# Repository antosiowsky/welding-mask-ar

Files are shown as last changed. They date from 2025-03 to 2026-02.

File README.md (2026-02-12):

# 🛡️ AR Welding Helmet
### Welding Helmet with Augmented Reality (AR) Supporting Electric Arc Welding






## 📖 Abstract
**Bachelor's Thesis Project**

The aim of this project was to design and construct a welding helmet utilizing **Augmented Reality (AR)** technology in **Video Pass-Through** mode. The system eliminates the risk of flash blindness by replacing the traditional optical path with a digital vision system using a **Global Shutter camera**.

The device features a custom-made PCB, a hybrid power supply with **Energy Harvesting** (solar panel), and environmental sensors (gas, light). The software runs on a **Raspberry Pi Zero 2 W**, utilizing direct framebuffer access to achieve low-latency stereoscopic vision.

---

## ⚙️ Hardware Architecture

### Core Components
* **SBC:** Raspberry Pi Zero 2 W
* **Camera:** Raspberry Pi Global Shutter Camera (Sony IMX296) + ND 2-1000 Filter
* **Display:** 5.5" HDMI AMOLED (1920x1080)
* **ADC:** MCP3008 (SPI interface)

### Sensors & Power
* **Gas Sensor:** MQ-07 (Carbon Monoxide)
* **Light Sensor:** Photoresistor (Trigger for AGC)
* **Energy Harvesting:** Polycrystalline Solar Panel
* **Power:** Li-Ion 18650 Cells + BMS

### Wiring Diagram
The electrical connection between the Raspberry Pi and the analog sensors via the MCP3008 ADC.
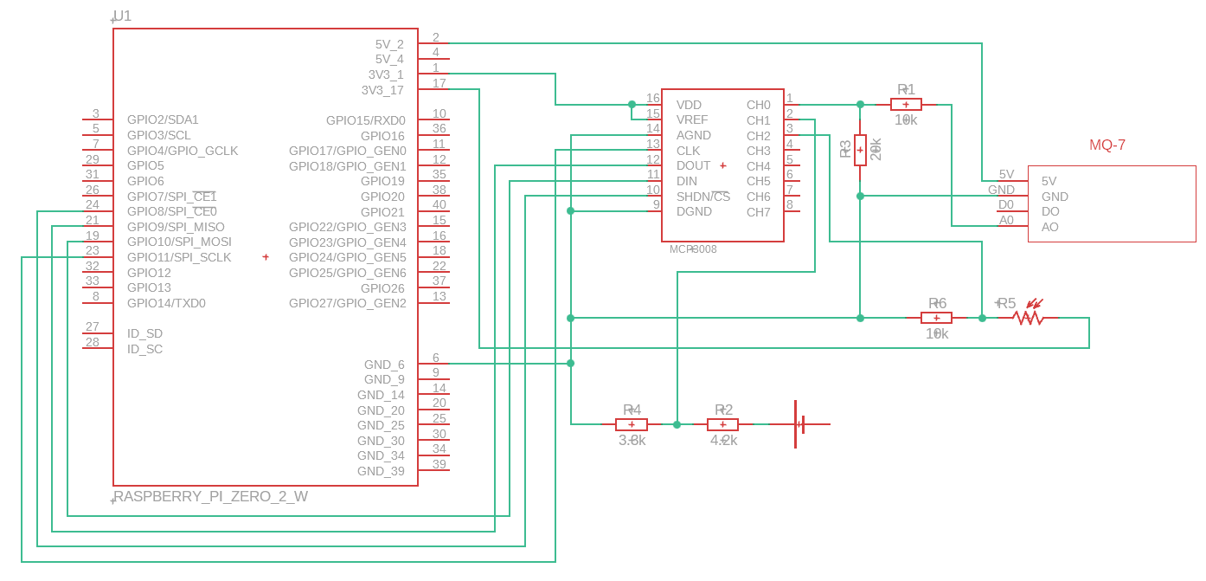
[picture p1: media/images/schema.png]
Schematic


### Custom PCB
The motherboard was designed in **Autodesk Fusion 360** and manufactured using a custom **laser ablation method** combined with chemical etching.

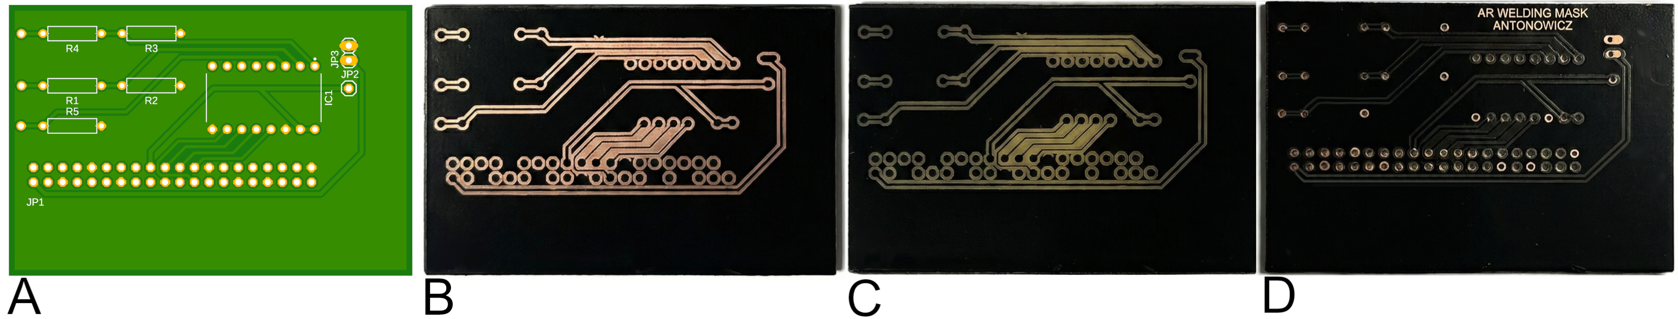
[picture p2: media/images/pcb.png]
Custom PCB Process


---

## 🛠️ Software & Algorithms

The control software is written in **Python** and optimized for the limited resources of the RPi Zero 2 W.

* **Direct Framebuffer Access:** Writing directly to `/dev/fb0` to bypass X11 overhead and minimize latency.
* **Adaptive Exposure Control (AEC):** Custom PID-like algorithm to adjust exposure time and gain in <100ms during arc ignition.
* **Multithreading:** Separated threads for image capture, data processing, and HUD rendering.
* **Stereoscopy:** Split-screen side-by-side rendering for VR optics compatibility.

### Dependencies
```text
opencv-python-headless
picamera2
spidev
numpy
```

## 📸 Gallery & Demo

### 1. The Prototype
The physical construction integrates standard welding protection with custom digital systems. The layout of the components is designed for optimal weight distribution and sensor accuracy.

| **Front View (External Sensors)** | **Internal Electronics & Optics** |
| :---: | :---: |
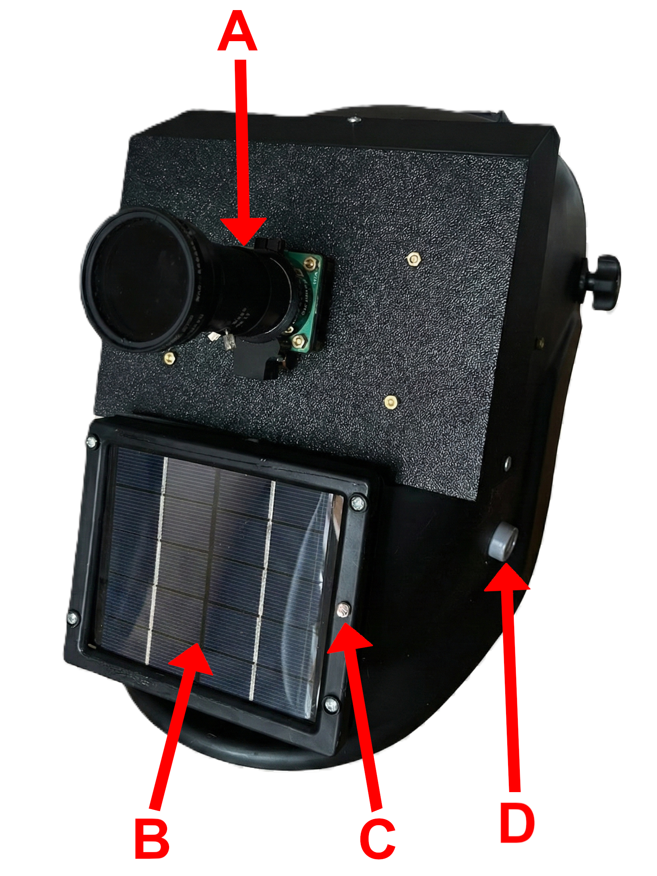
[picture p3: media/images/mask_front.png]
Front View
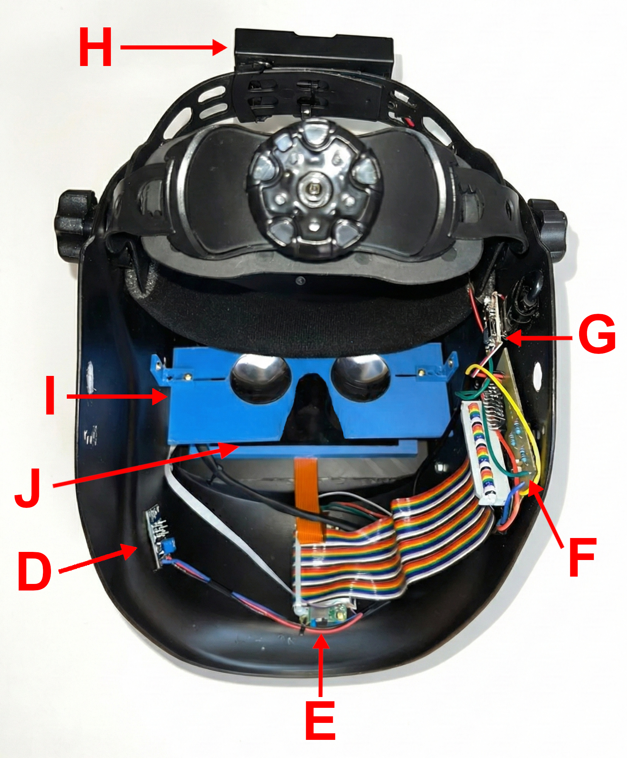
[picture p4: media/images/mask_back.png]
Internal Electronics
|  |  |

#### **Component Legend:**

**Front Panel (External):**
* **A) Camera Optical Assembly:** Raspberry Pi Global Shutter camera with UV protection and adjustable ND 2-1000 filter.
* **B) Solar Panel:** Polycrystalline silicon cell for Energy Harvesting.
* **C) Photoresistor:** Light intensity sensor acting as a trigger for exposure control algorithms.
* **D) MQ-07 Gas Sensor:** Carbon Monoxide monitoring inlet.

**Internal Layout:**
* **E) Central Processing Unit:** Raspberry Pi Zero 2 W.
* **F) Custom PCB:** Motherboard with integrated ADC, manufactured via laser ablation.
* **G) Power Management (BMS):** Module for energy distribution and solar charging control.
* **H) Energy Storage:** High-capacity Li-Ion 18650 battery pack.
* **I) VR Lens Assembly:** Biconvex lenses for comfortable eye accommodation at close display proximity.
* **J) 5.5" LCD Display:** Full HD panel responsible for rendering the AR HUD interface.

---

### 2. AR HUD Interface (Scenarios)
Visualization of the real-time data overlaid on the welder's field of view.

| **Arc Ignition (Initial Flash)** | **Stabilized View (Active AGC)** | **Gas Alarm (Safety Warning)** |
| :---: | :---: | :---: |
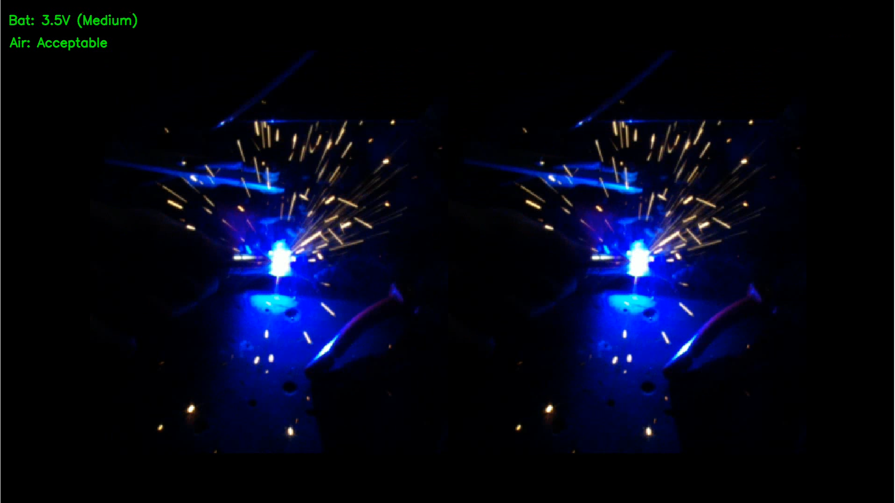
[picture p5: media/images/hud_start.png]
Flash
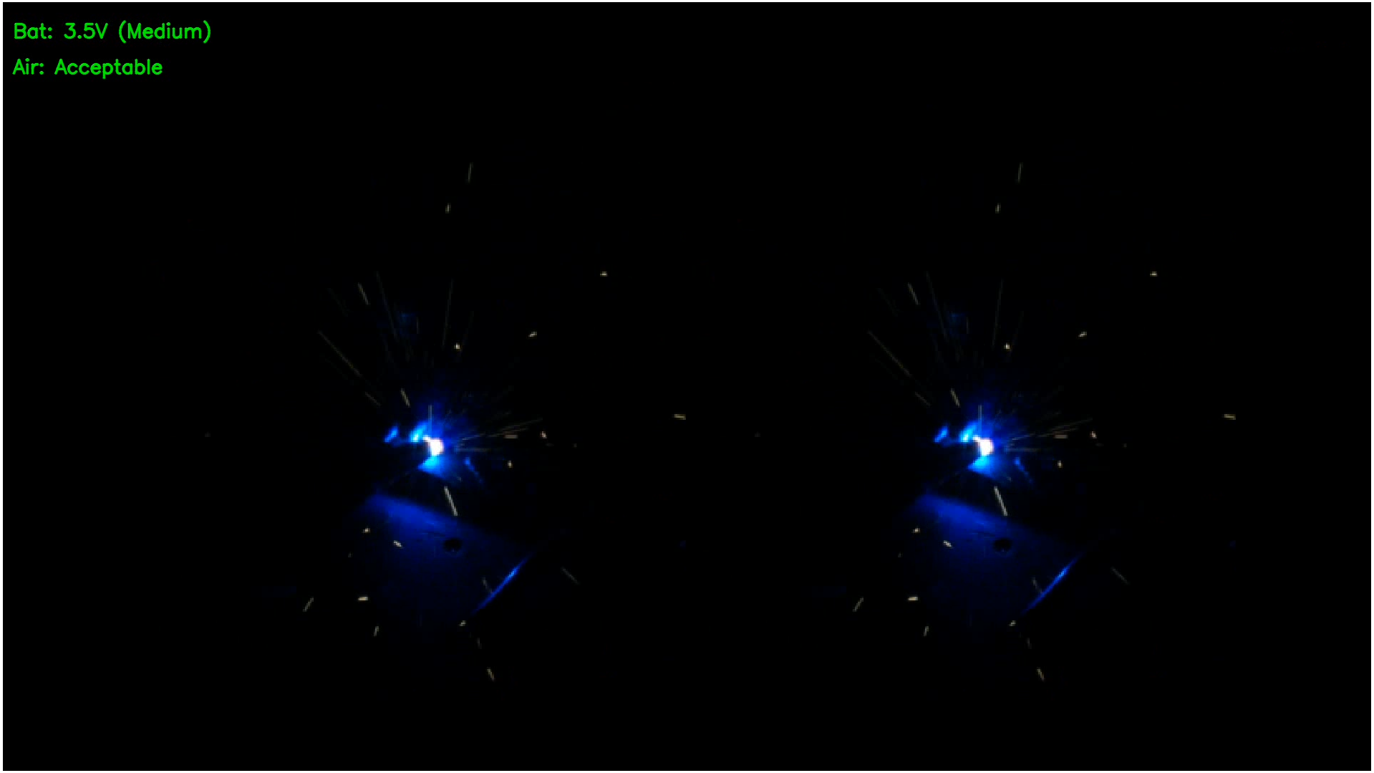
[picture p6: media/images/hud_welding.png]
Welding
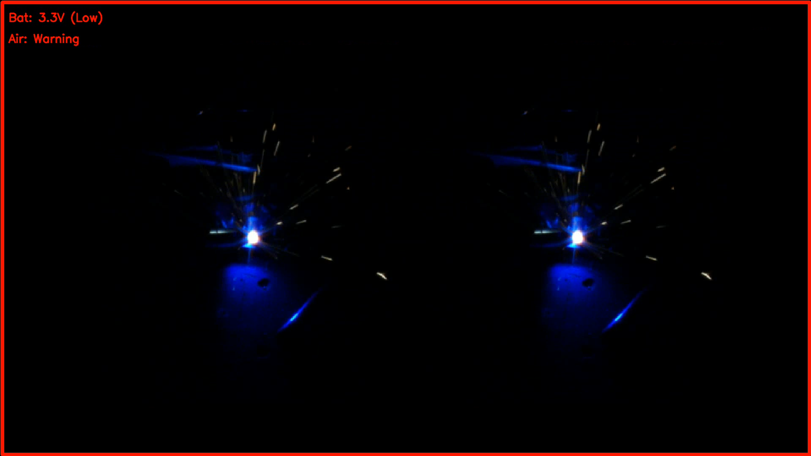
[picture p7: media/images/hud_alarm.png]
Alarm
|  |  |  |

### 3. Video Demonstration
System operation in real-time. The GIF below demonstrates the Adaptive Gain Control (AGC) reacting to the welding arc.

<div align="center">
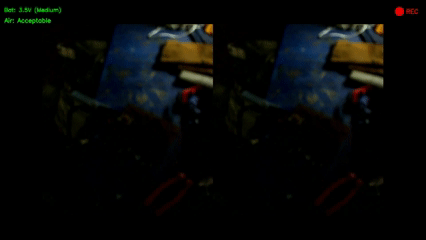
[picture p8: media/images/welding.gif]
Welding Demo GIF
  
</div>

> **Note:** The high-quality raw video file is available in the repository at: `media/video/demo.mp4`

---

## 📊 System Performance
Key metrics measured during validation tests:

| Metric | Result | Notes |
| :--- | :--- | :--- |
| **Glass-to-Glass Latency** | **60 - 90 ms** | Dependent on exposure time. Acceptable for MIG/MAG welding. |
| **Frame Rate** | **18 - 20 FPS** | Stable limit of RPi Zero 2W with dual-view rendering. |
| **Solar Charging** | **~150 mA** | Measured under welding arc simulation. Acts as a Range Extender. |
| **Gas Response Time** | **< 2.0 s** | Tested with butane/propane mixture. |

## 🏗️ Mechanical Design

The entire mechanical structure, including electronics enclosures and custom mounts, was designed in **Autodesk Fusion 360**. All components were optimized for 3D printing using **PET-G** and **PLA** filaments.

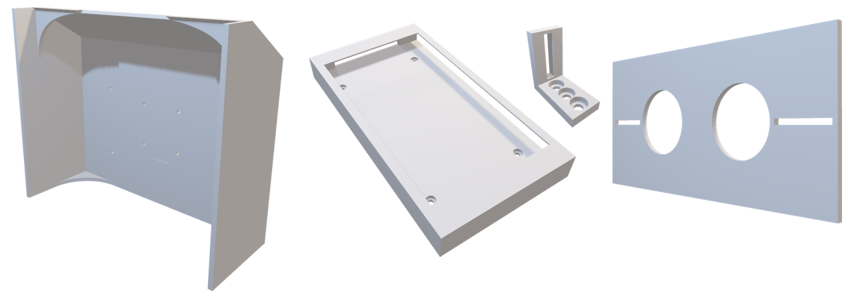
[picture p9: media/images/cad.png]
CAD Model


---

## 📄 License & Information

This project is open-source and available under the **MIT License**.

* **Author:** Jakub Antonowicz
* **University:** Silesian University of Technology (*Politechnika Śląska*)
* **Year:** 2026

---

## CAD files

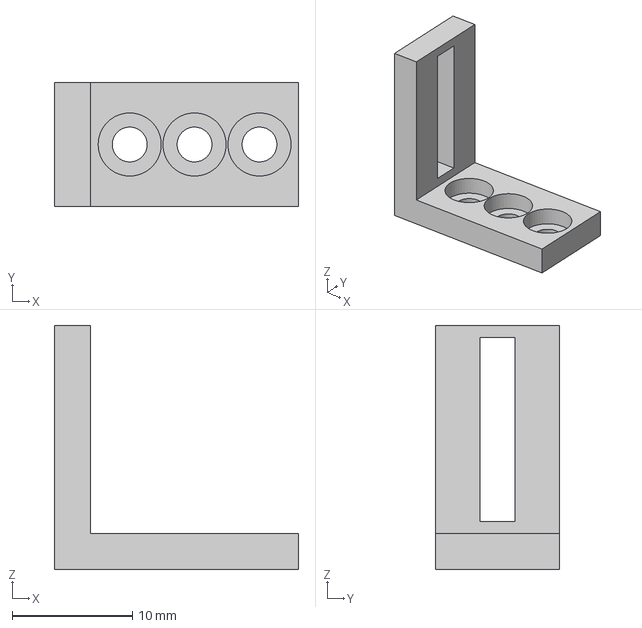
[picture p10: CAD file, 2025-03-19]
3d-models/support-angle.3mf
20.3 x 10.3 x 20.3 mm

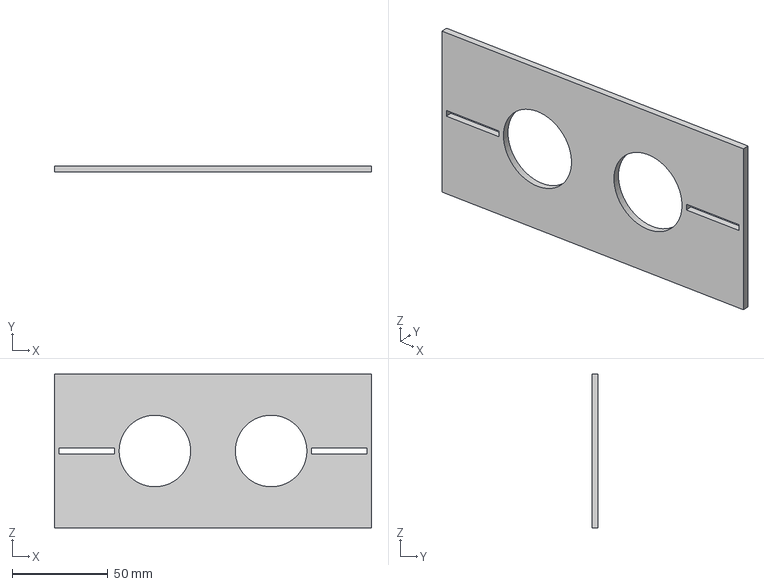
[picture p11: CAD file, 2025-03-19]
3d-models/case-lens.3mf
165.3 x 3.20 x 80.3 mm

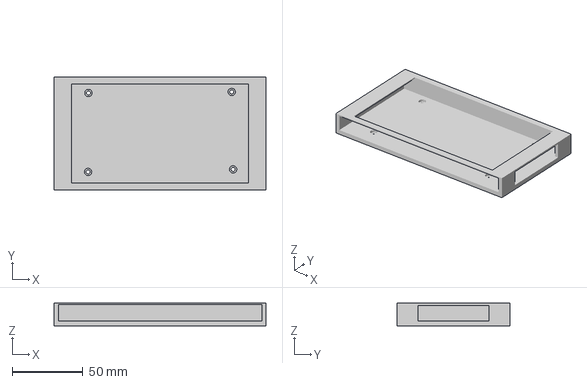
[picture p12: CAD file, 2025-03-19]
3d-models/case-display.3mf
150.0 x 80.0 x 16.0 mm

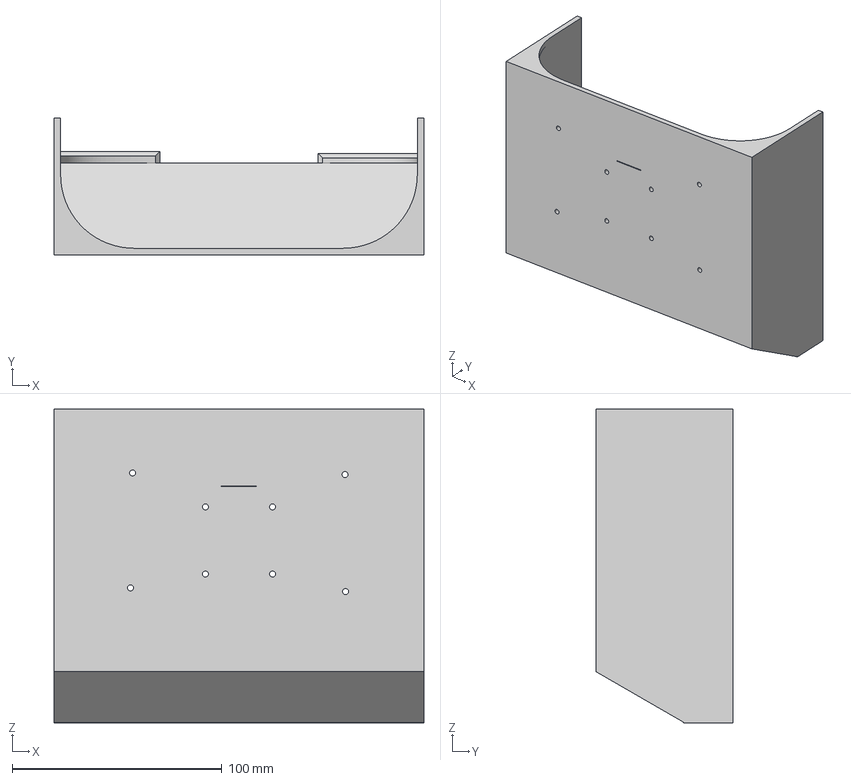
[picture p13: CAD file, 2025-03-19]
3d-models/pannel-front.3mf
176.6 x 65.3 x 149.7 mm

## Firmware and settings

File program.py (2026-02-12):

#!/usr/bin/env python3
"""
AR Welding Mask - Main Program
Real-time camera feed with sensor overlay for AR goggles display
Displays dual-view (VR mode) with battery and air quality (MQ-07)
"""

import numpy as np
from picamera2 import Picamera2
import cv2
import os
import time
from threading import Thread, Lock
import spidev
import sys
from datetime import datetime

# ============================================================================
# CONFIGURATION
# ============================================================================

# Framebuffer resolution (display)
FB_WIDTH, FB_HEIGHT = 1920, 1080

# Camera preview size (half-width for dual view) - reduced for better FPS on RPi Zero
CAMERA_WIDTH = 320  # Ultra-low res for speed (320x360 per eye = 640x360 dual)
CAMERA_HEIGHT = 360

# SPI configuration for MCP3008
SPI_BUS = 0
SPI_DEVICE = 0
SPI_SPEED = 1350000  # 1.35 MHz

# MCP3008 channel mapping (as per sensor_test.py)
CH_BATTERY = 0      # 18650 battery with 10k/20k voltage divider
CH_MQ07 = 1         # MQ-07 CO sensor with 2.2k/3.3k voltage divider
CH_LIGHT = 2        # Photoresistor with 10k resistor

# Display settings
DISPLAY_SCALE = 0.8  # Scale factor for image frame within framebuffer (80% of screen)
DEBUG_MODE = True   # Set to True to print FPS and sensor values to console and show cv2 preview

# Camera exposure/brightness adjustment based on light
LIGHT_ADJUST_ENABLED = True
LIGHT_ADJUST_INTERVAL = 0.15    # Adjust every 0.15s (very fast adaptive response)
LIGHT_THRESHOLD_DIM = 150       # Below this: increase exposure
LIGHT_THRESHOLD_BRIGHT = 850    # Above this: decrease exposure

# Adaptive gain controller (PID-like smooth adjustment instead of threshold jumps)
ADAPTIVE_GAIN_ENABLED = True
GAIN_TARGET_LIGHT = 550          # Target light level for neutral gain (natural light)
GAIN_MIN = 1.0                   # Minimum gain
GAIN_MAX = 16.0                  # Maximum gain
GAIN_RATE = 0.15                # Smooth adjustment rate (0.0-1.0, lower = smoother)
EXPOSURE_TIME_MIN = 1000         # Min exposure time (1ms) - reduce latency
EXPOSURE_TIME_MAX = 20000        # Max exposure time (20ms)

# Performance settings
TARGET_FPS = 18                 # Target frame rate (reduced for sensor reads + larger display)
FRAMEBUFFER_CACHE = None        # Cache framebuffer file handle
FRAME_TIME_BUDGET = 1.0 / TARGET_FPS  # Time budget per frame (seconds)
MIN_FRAME_TIME = 0.003  # Minimum sleep to avoid CPU spin

# Recording settings
RECORDING_TRIGGER_THRESHOLD = 50    # Light level below this triggers recording start/stop
RECORDING_TRIGGER_DURATION = 3.0    # Seconds to hold photoresistor covered
RECORDING_OUTPUT_DIR = "/home/maska/recordings"  # Directory for saved recordings
RECORDING_FPS = 18                  # Recording FPS (match target FPS)
RECORDING_CODEC = "mp4v"            # MP4 codec (MJPEG: 'MJPG', H264: 'avc1', MPEG4: 'mp4v')

# ============================================================================
# SENSOR CALIBRATION (from sensor_test.py)
# ============================================================================

VREF = 3.3  # MCP3008 reference voltage

def read_adc(channel):
    """
    Read ADC value from MCP3008 channel.
    
    Args:
        channel (int): ADC channel (0-7)
        
    Returns:
        int: Digital value (0-1023)
    """
    if channel < 0 or channel > 7:
        return -1
    
    # MCP3008 requires 3 bytes: start bit, single-ended mode, channel selection
    adc = spi.xfer2([1, (8 + channel) << 4, 0])
    data = ((adc[1] & 3) << 8) + adc[2]
    return data

def calculate_battery_voltage(adc_value):
    """
    Calculate battery voltage from ADC reading.
    Voltage divider: 10kΩ to GND, 20kΩ to battery
    Vout = Vin * (10k / 30k) => Vin = Vout * 3
    
    Args:
        adc_value (int): ADC reading (0-1023)
        
    Returns:
        tuple: (voltage, status_text, is_critical)
    """
    v_measured = (adc_value / 1023.0) * VREF
    v_battery = v_measured * 3.0
    
    # Battery status
    if v_battery > 4.1:
        status = "Full"
        critical = False
    elif v_battery > 3.7:
        status = "Good"
        critical = False
    elif v_battery > 3.4:
        status = "Medium"
        critical = False
    elif v_battery > 3.0:
        status = "Low"
        critical = True
    else:
        status = "Critical"
        critical = True
    
    return v_battery, status, critical

def calculate_mq07_status(adc_value):
    """
    Calculate MQ-07 CO sensor status from ADC reading.
    Voltage divider: 2.2kΩ to GND, 3.3kΩ to sensor
    Vout = Vin * (2.2k / 5.5k) => Vin = Vout * 2.5
    
    Calibration:
    - 0.8V or less: Good (OK)
    - 1.4V: Acceptable (warning)
    - 2.8V+: Dangerous (alarm)
    
    Args:
        adc_value (int): ADC reading (0-1023)
        
    Returns:
        tuple: (voltage, status_text, is_dangerous)
    """
    v_measured = (adc_value / 1023.0) * VREF
    v_sensor = v_measured * 2.5
    
    # Air quality status - removed "Very Good"
    if v_sensor <= 0.8:
        status = "Good"
        dangerous = False
    elif v_sensor < 1.4:
        status = "Acceptable"
        dangerous = False
    elif v_sensor < 2.8:
        status = "Warning"
        dangerous = True
    else:
        status = "DANGER!"
        dangerous = True
    
    return v_sensor, status, dangerous

def calculate_light_level(adc_value):
    """
    Calculate light level from photoresistor ADC reading.
    
    Calibration:
    - 0: darkness
    - 602: natural light
    - 950: flashlight (very bright)
    
    Args:
        adc_value (int): ADC reading (0-1023)
        
    Returns:
        tuple: (adc_value, status_text)
    """
    # Light status based on calibration
    if adc_value < 100:
        status = "Dark"
    elif adc_value < 400:
        status = "Dim"
    elif adc_value < 750:
        status = "Normal"
    elif adc_value < 950:
        status = "Bright"
    else:
        status = "Very Bright"
    
    return adc_value, status

# ============================================================================
# FRAME CAPTURE THREAD
# ============================================================================

class FrameProcessor:
    """Thread-safe camera frame capture."""
    
    def __init__(self, picam2):
        self.picam2 = picam2
        self.running = True
        self.frame = None
        self.lock = Lock()
        self.thread = Thread(target=self._capture_frames, daemon=True)
        self.thread.start()
    
    def _capture_frames(self):
        """Continuously capture frames from camera."""
        while self.running:
            try:
                captured = self.picam2.capture_array()
                with self.lock:
                    self.frame = captured
            except Exception as e:
                print(f"Frame capture error: {e}")
                time.sleep(0.1)
    
    def get_frame(self):
        """Get the latest captured frame (thread-safe)."""
        with self.lock:
            return self.frame.copy() if self.frame is not None else None
    
    def stop(self):
        """Stop the capture thread."""
        self.running = False
        self.thread.join(timeout=2.0)

# ============================================================================
# DISPLAY RENDERING
# ============================================================================

# Pre-calculate frame positioning
frame_width = int(FB_WIDTH * DISPLAY_SCALE)
frame_height = int(FB_HEIGHT * DISPLAY_SCALE)
x_offset = (FB_WIDTH - frame_width) // 2
y_offset = (FB_HEIGHT - frame_height) // 2

# Create background template (reused to avoid allocations)
background_template = np.zeros((FB_HEIGHT, FB_WIDTH, 3), dtype=np.uint8)

# Pre-allocate RGB565 buffer (reused for framebuffer writes)
rgb565_buffer = np.zeros((FB_HEIGHT, FB_WIDTH), dtype=np.uint16)

def render_recording_icon(image, recording_active):
    """
    Render recording icon (red circle) on HUD.
    
    Args:
        image (ndarray): Image to render icon on
        recording_active (bool): Whether recording is active
    """
    if not recording_active:
        return
    
    # Red circle in top-right corner with REC text
    icon_x = FB_WIDTH - 120
    icon_y = 50
    
    # Pulsing effect (blink every 0.5 seconds)
    if int(time.time() * 2) % 2 == 0:
        cv2.circle(image, (icon_x, icon_y), 20, (0, 0, 255), -1)  # Filled red circle
        cv2.putText(image, "REC", (icon_x + 30, icon_y + 10), 
                   cv2.FONT_HERSHEY_SIMPLEX, 0.9, (0, 0, 255), 2, cv2.LINE_AA)

def render_osd(image, battery_voltage, battery_status, battery_critical,
               mq07_voltage, mq07_status, mq07_dangerous,
               light_value, light_status, recording_active=False):
    """
    Render on-screen display (OSD) with clean layout.
    Shows battery, air quality, light level, recording icon. Red border if danger.
    
    Args:
        image (ndarray): Image to render text on
        battery_voltage (float): Battery voltage
        battery_status (str): Battery status text
        battery_critical (bool): Battery critical flag
        mq07_voltage (float): MQ-07 voltage
        mq07_status (str): Air quality status
        mq07_dangerous (bool): Air quality danger flag
        light_value (int): Light ADC value
        light_status (str): Light status text
        recording_active (bool): Whether recording is active
    """
    font = cv2.FONT_HERSHEY_SIMPLEX
    font_scale = 0.9  # Larger font for better visibility
    thickness = 2
    
    # Battery info (top-left)
    battery_color = (0, 0, 255) if battery_critical else (0, 255, 0)
    cv2.putText(image, f"Bat: {battery_voltage:.1f}V ({battery_status})",
                (20, 50), font, font_scale, battery_color, thickness, cv2.LINE_AA)
    
    # Air quality (top-left, below battery) - no voltage display
    air_color = (0, 0, 255) if mq07_dangerous else (0, 255, 0)
    cv2.putText(image, f"Air: {mq07_status}",
                (20, 100), font, font_scale, air_color, thickness, cv2.LINE_AA)
    
    # Light level info hidden (commented out)
    
    # Recording icon
    render_recording_icon(image, recording_active)
    
    # RED BORDER if danger
    if mq07_dangerous:
        cv2.rectangle(image, (5, 5), (FB_WIDTH - 5, FB_HEIGHT - 5), (0, 0, 255), 8)

def display_on_framebuffer(double_frame, battery_voltage, battery_status, battery_critical,
                            mq07_voltage, mq07_status, mq07_dangerous,
                            light_value, light_status, fb_handle=None, recording_active=False):
    """
    Render dual-view frame with OSD to framebuffer.
    Optimized: reuses buffers, minimal copies, cached file handle, fast resize.
    
    Args:
        double_frame (ndarray): Dual camera view (side-by-side)
        battery_voltage, battery_status, battery_critical: Battery info
        mq07_voltage, mq07_status, mq07_dangerous: Air quality info
        light_value, light_status: Light level info
        fb_handle: Cached framebuffer file handle (optional)
        recording_active (bool): Whether recording is active
    
    Returns:
        ndarray: The final rendered frame with OSD (for recording)
    """
    global rgb565_buffer
    
    # Resize to fit frame area (use INTER_NEAREST for maximum speed on embedded)
    resized_image = cv2.resize(double_frame, (frame_width, frame_height), interpolation=cv2.INTER_NEAREST)

    # Copy background and place resized image
    background = background_template.copy()
    background[y_offset:y_offset + frame_height, x_offset:x_offset + frame_width] = resized_image

    # Render OSD using existing renderer
    try:
        render_osd(background, battery_voltage, battery_status, battery_critical,
                   mq07_voltage, mq07_status, mq07_dangerous,
                   light_value, light_status, recording_active)
    except Exception:
        # fallback: minimal text if render_osd fails
        try:
            cv2.putText(background, f'Air: {mq07_status}', (230, 150), cv2.FONT_HERSHEY_SIMPLEX, 1, (0, 255, 0), 2)
            cv2.putText(background, f'Light: {light_value}', (50, 100), cv2.FONT_HERSHEY_SIMPLEX, 1, (0, 255, 0), 2)
        except Exception:
            pass

    # Convert to RGB565 (optimized: reuse buffer when possible)
    try:
        rgb565_image = cv2.cvtColor(background, cv2.COLOR_BGR2BGR565)
    except Exception as e:
        if DEBUG_MODE:
            print('DEBUG: Color conversion to BGR565 failed:', e)
        rgb565_image = background

    # Write to framebuffer (use cached handle if provided)
    try:
        if fb_handle is not None:
            fb_handle.seek(0)
            fb_handle.write(rgb565_image.tobytes())
            fb_handle.flush()
        else:
            with open('/dev/fb0', 'wb') as fb:
                fb.write(rgb565_image.tobytes())
    except Exception as e:
        if DEBUG_MODE:
            print('DEBUG: Framebuffer write error:', e)
    
    # Return the final frame for recording
    return background

# ============================================================================
# CAMERA CONTROL
# ============================================================================

# Global state for adaptive gain controller
adaptive_gain_state = {
    'current_gain': 6.0,
    'current_exposure': 10000,
    'last_update': 0
}

def adjust_camera_exposure(picam2, light_value):
    """
    Adaptive gain controller (PID-like) for smooth, flicker-free exposure.
    Replaces threshold-based jumps with smooth interpolation.
    Reduces latency with lower ExposureTime and NoiseReduction disabled during bright.
    
    Args:
        picam2: Picamera2 instance
        light_value (int): Light ADC value
    """
    if not LIGHT_ADJUST_ENABLED:
        return
    
    try:
        # Adaptive gain: smooth controller based on distance from target
        error = GAIN_TARGET_LIGHT - light_value
        
        # Calculate target gain (proportional controller)
        # error = +300 (too dark) => high gain
        # error = 0 (perfect) => medium gain
        # error = -300 (too bright) => low gain
        gain_normalize = error / 300.0  # Normalize error to [-1, 1] range
        
        # Target gain: mid-range at neutral, scales toward extremes
        target_gain = 6.0 + (gain_normalize * 5.0)  # 1-11 range
        target_gain = max(GAIN_MIN, min(GAIN_MAX, target_gain))  # Clamp
        
        # Smooth interpolation toward target (prevents jitter)
        new_gain = adaptive_gain_state['current_gain'] * (1.0 - GAIN_RATE) + target_gain * GAIN_RATE
        new_gain = max(GAIN_MIN, min(GAIN_MAX, new_gain))
        
        # Adaptive exposure time (reduce latency by lowering exposure in bright, keeping it higher in dark)
        if light_value > 750:  # Very bright: minimal exposure for low latency
            target_exposure = EXPOSURE_TIME_MIN + 1000  # ~2-3ms
        elif light_value > 550:  # Bright/Normal: medium exposure
            target_exposure = 7000  # ~7ms
        elif light_value > 300:  # Dim: longer exposure
            target_exposure = 11000  # ~11ms
        else:  # Very dark: maximum exposure
            target_exposure = EXPOSURE_TIME_MAX  # ~20ms
        
        # Smooth exposure adjustment
        new_exposure = int(adaptive_gain_state['current_exposure'] * 0.8 + target_exposure * 0.2)
        new_exposure = max(EXPOSURE_TIME_MIN, min(EXPOSURE_TIME_MAX, new_exposure))
        
        # Only update if change is significant (avoid redundant calls)
        if abs(new_gain - adaptive_gain_state['current_gain']) > 0.1 or \
           abs(new_exposure - adaptive_gain_state['current_exposure']) > 500:
            
            controls = {
                "AnalogueGain": new_gain,
                "ExposureTime": new_exposure,
                "Brightness": 0.0 if light_value > 550 else (0.05 if light_value < 250 else 0.0),
                "Contrast": 1.1 if light_value > 550 else (1.3 if light_value < 250 else 1.2)
            }
            
            picam2.set_controls(controls)
            adaptive_gain_state['current_gain'] = new_gain
            adaptive_gain_state['current_exposure'] = new_exposure
            
            if DEBUG_MODE and light_value % 30 == 0:  # Log every ~30 samples
                print(f"Adaptive: light={light_value} -> gain={new_gain:.1f} exp={new_exposure}µs")
    
    except Exception as e:
        if DEBUG_MODE:
            print(f"Camera control error: {e}")

# ============================================================================
# MAIN PROGRAM
# ============================================================================
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

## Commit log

2025-12-05 todo: add battery %
    [case-display.3mf, case-lens.3mf, pannel-front.3mf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]
2026-02-12 Revise README with project overview and details
    Updated the README to include project details, features, hardware components, software tools, and installation instructions for the AR welding helmet system.
2026-02-12 Update README with project description
    Added project description for Smart Welding Helmet.
2026-02-12 Enhance README with wiring diagram and performance metrics
    Added wiring diagram and system performance metrics to README.
